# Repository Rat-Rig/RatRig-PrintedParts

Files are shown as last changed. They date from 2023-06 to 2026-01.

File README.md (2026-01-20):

<a href="https://ratrig.com/">
    RatRig logo RatRig
</a>

# Printed Parts Repository

## Overview
This repository contains STL files pertaining to all existing, as well as obsolete, 3D-printed elements used in our products.

Each design is named with a unique SKU to distinguish it, along with a version number and a date. In the case where a fresh revision becomes necessary (such as rectifying an issue with the part, significant enhancement, or improving the printability), a new part is released with an incremented version number.

In cases where the part undergoes a complete redesign, the old SKU is retired and a new SKU is assigned to the new design.

In all cases, any STL which has been replaced is relocated into a subfolder labeled "deprecated".

## Repository Layout
- Generic parts which are shared across projects are stored either in 'Alignment Tools' or 'Miscellaneous'
- Unique parts for each project are stored in the project subfolder
- Deprecated parts are stored within a 'Deprecated' subfolder
```
├── Alignment-Tools/
│   ├── PP000001-align_2020_mgn12_V01_20230627.stl
│   ├── PP000002-align_2020_mgn15_V01_20230627.stl
│   └── ...
├── ...
├── V-Core-3.1/
├── V-Hive/
└── V-Minion/
    ├── Deprecated/
    │   └── PP000028-shroud_V01_20230628.stl
    ├── PP000013-40mm_fan_cage_V01_20230628.stl
    └── ...
```
## Downloads
Individual STL files can be downloaded directly from this repository. Alternately, printed part packs for each product can be downloaded at [files.ratrig.com](https://files.ratrig.com/printed_parts/).

## License
All files contained within this repository are licensed under the [Creative Commons Attribution-NonCommercial-ShareAlike 4.0 International Public License](https://creativecommons.org/licenses/by-nc-sa/4.0/). See LICENSE for the full details.

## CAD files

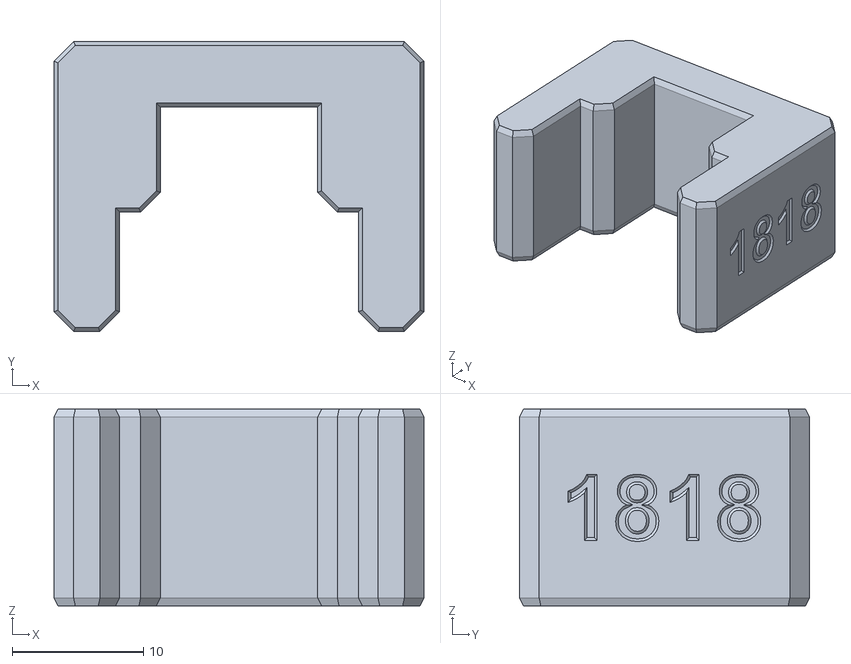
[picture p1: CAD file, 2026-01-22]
Alignment-Tools/PP000407-align_1818_mgn12_V01_20251020.stl
28.2 x 22.1 x 15.0

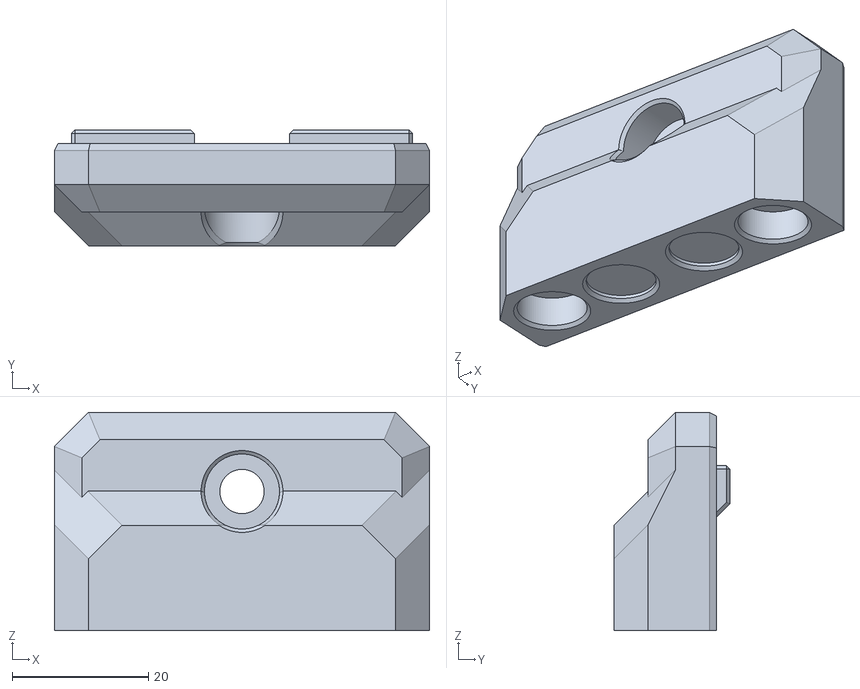
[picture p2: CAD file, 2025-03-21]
CNC-Enclosure/PP000385-cnc_enclosure_magnet_frame_3030_V01_20250122.stl
55.0 x 17.0 x 32.0

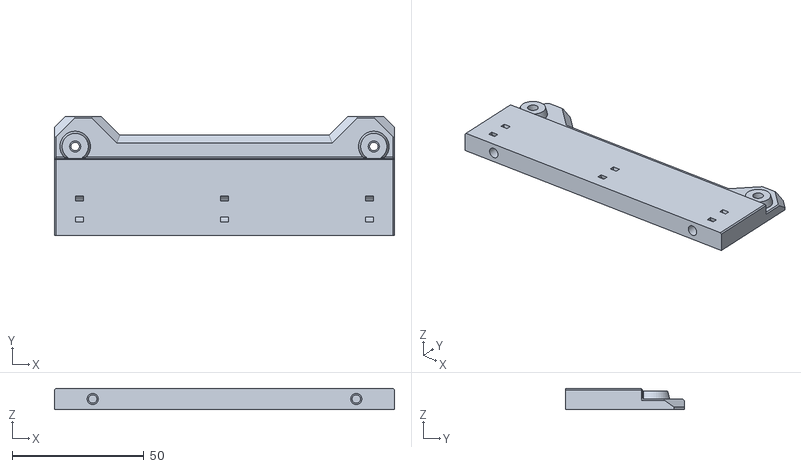
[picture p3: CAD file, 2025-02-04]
Compact-CNC-Electronics-Enclosure/PP000371-compact_cnc_electronics_btt_rodent_V02_20250131.stl
129.0 x 45.0 x 8.00

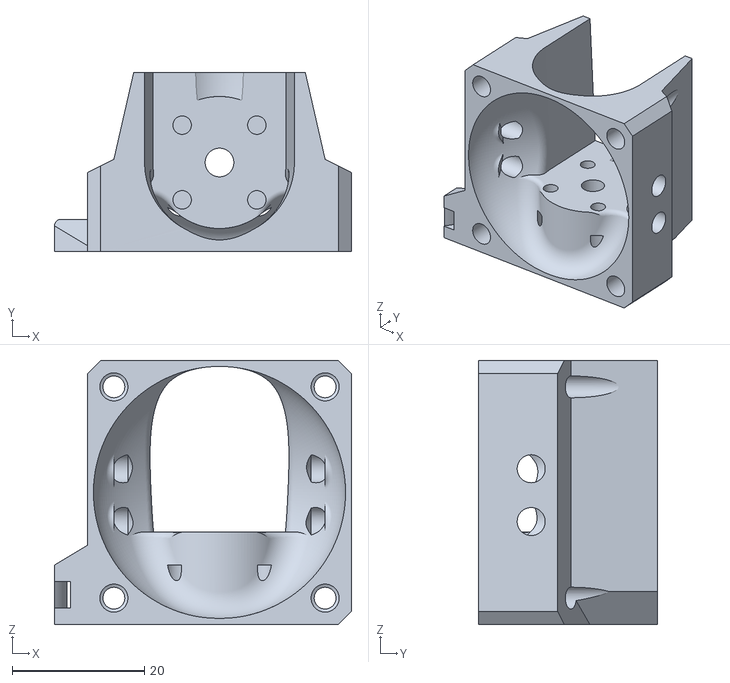
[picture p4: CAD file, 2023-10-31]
EVA-3.0.2/PP000260-hotend_rapido_fi_V01_20231031.stl
45.0 x 27.1 x 40.0

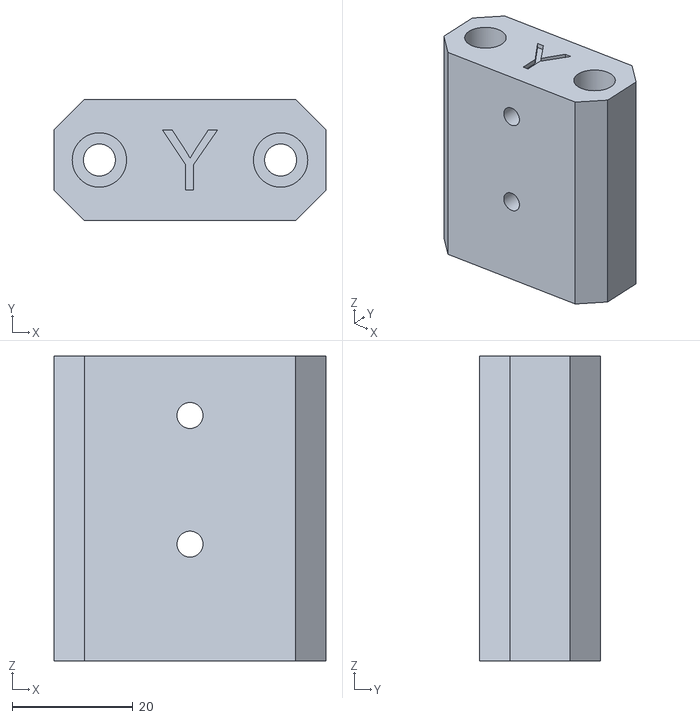
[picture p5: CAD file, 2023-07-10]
KillerBee/PP000070-K-Y-Axis-Gantry-DragChain-Mount_V01_20230710.stl
45.0 x 20.0 x 50.5

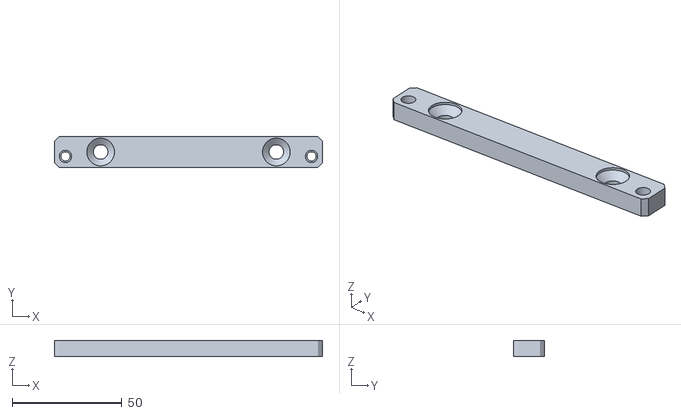
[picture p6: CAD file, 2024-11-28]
Mill/PP000382-mill_vfd_mount_V01_20241127.stl
122.0 x 14.0 x 7.50

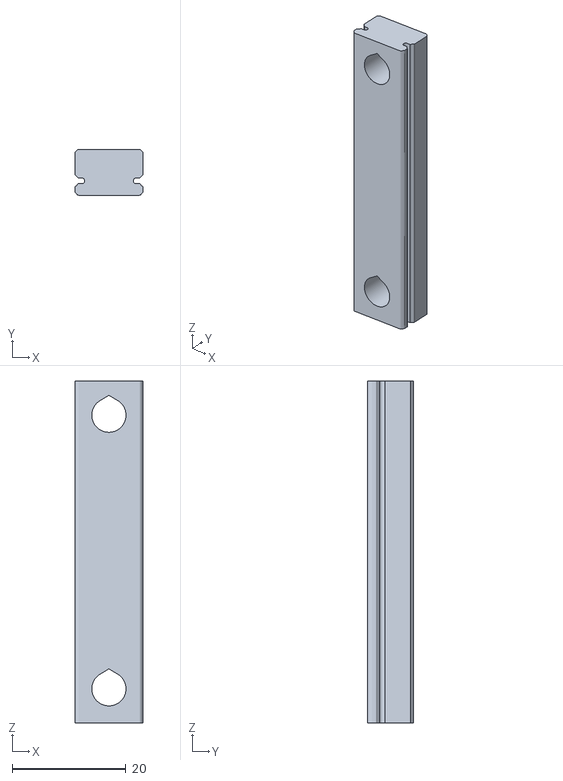
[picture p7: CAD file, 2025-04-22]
Miscellaneous/PP000390-mgn12_carriage_holder_V01_20250422.stl
12.0 x 8.00 x 60.0

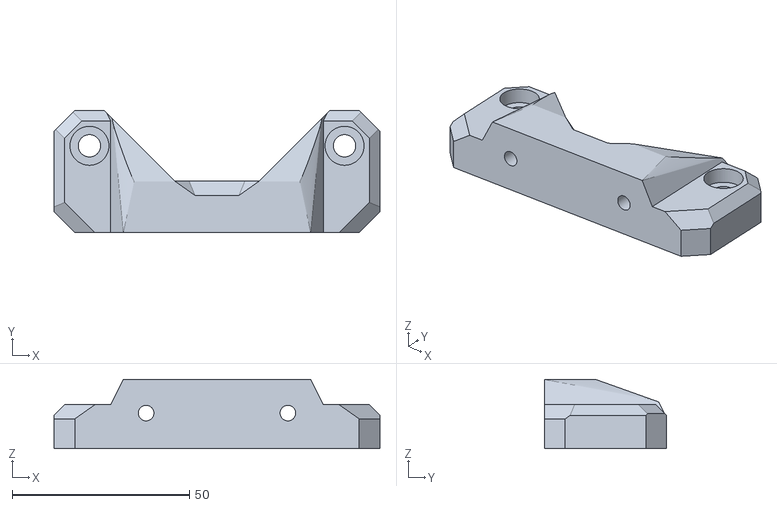
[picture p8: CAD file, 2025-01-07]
Rat-Pack/PP000378-ratpack_mount_large_V01_20241115.stl
92.0 x 34.5 x 19.5

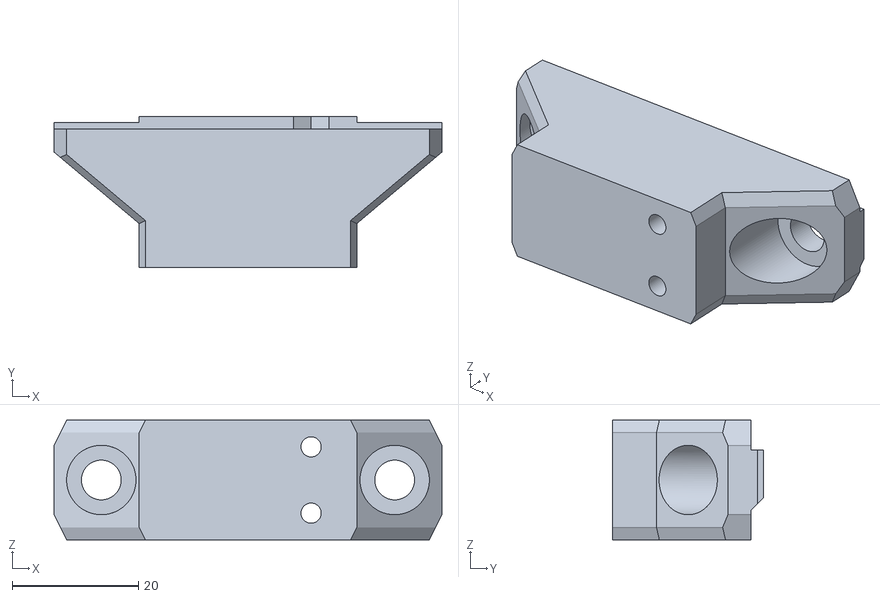
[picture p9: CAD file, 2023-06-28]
StrongHold-ONE/PP000055-sh_y_endstop_mount_V01_20230628.stl
61.5 x 24.0 x 19.0

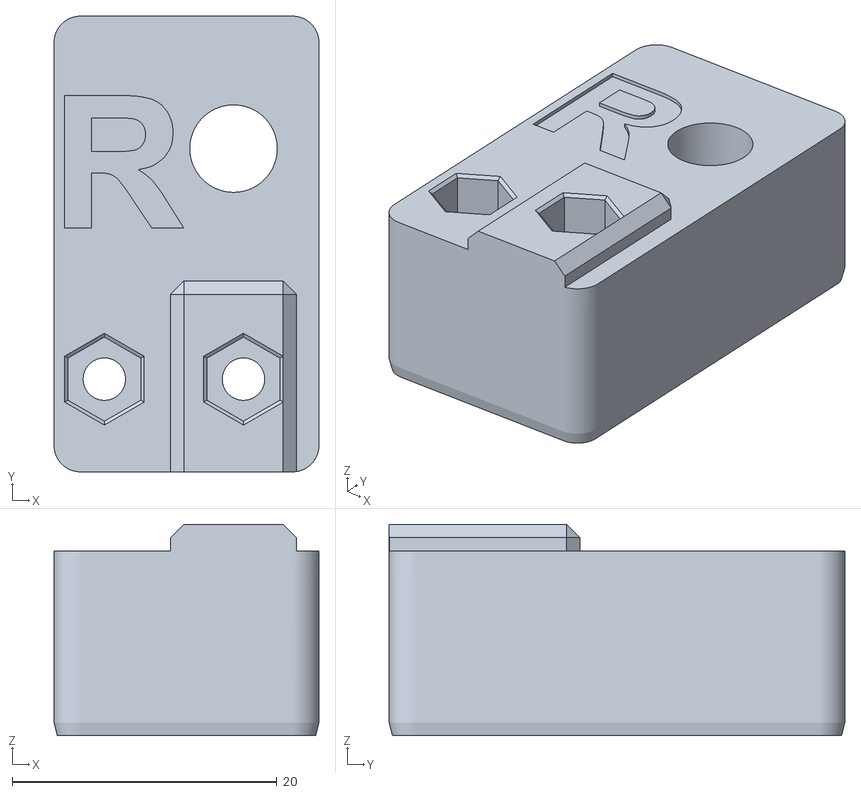
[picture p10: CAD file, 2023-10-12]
StrongHold-PRO/PP000242-sh_pro_y_endstop_right_V01_20231012.stl
20.0 x 34.4 x 15.9

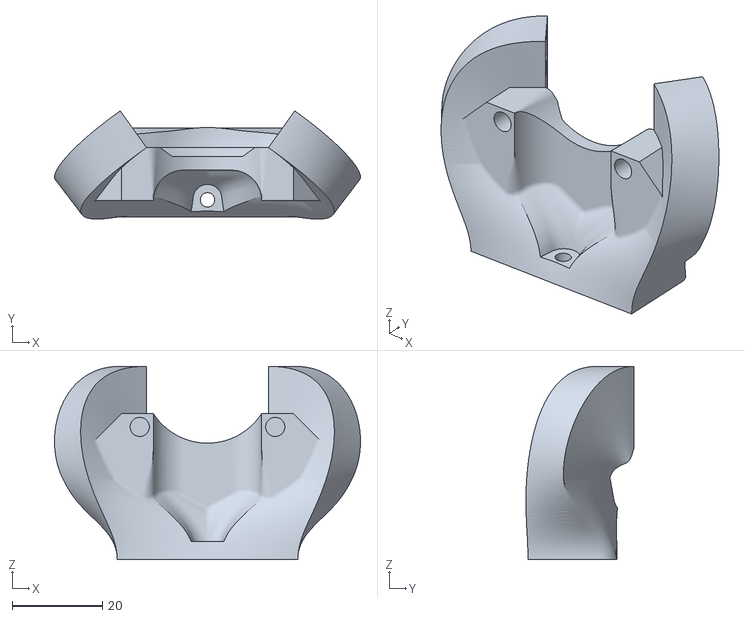
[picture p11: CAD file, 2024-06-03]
Toolheads/Rat Rig V-Core 3.1/PP000348-rr_toolhead_vc3_duct_V01_20240531.stl
67.8 x 24.0 x 42.8

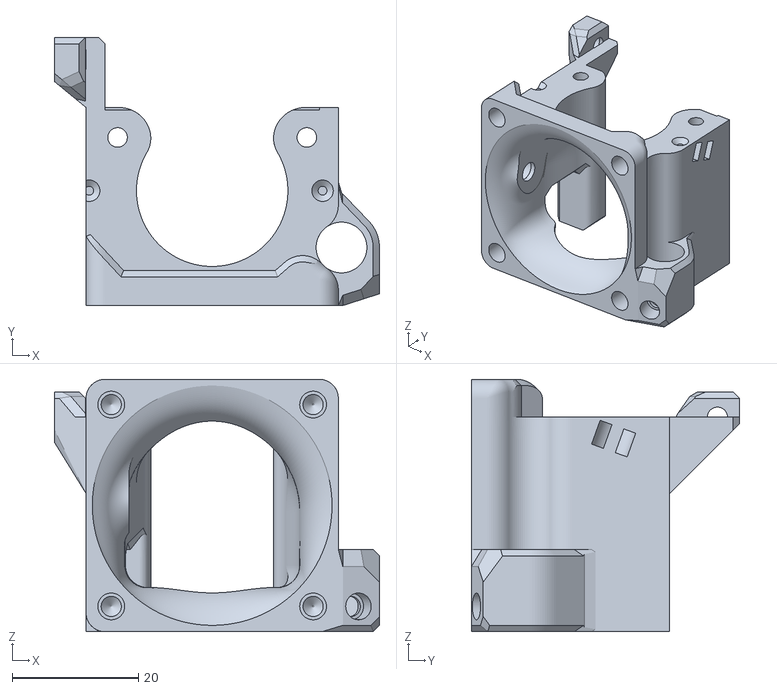
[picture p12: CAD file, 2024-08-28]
Toolheads/Rat Rig V-Core 4.0/PP000316-rr_toolhead_vc4_front_idex_t0_V01_20240813.stl
51.5 x 42.5 x 40.0

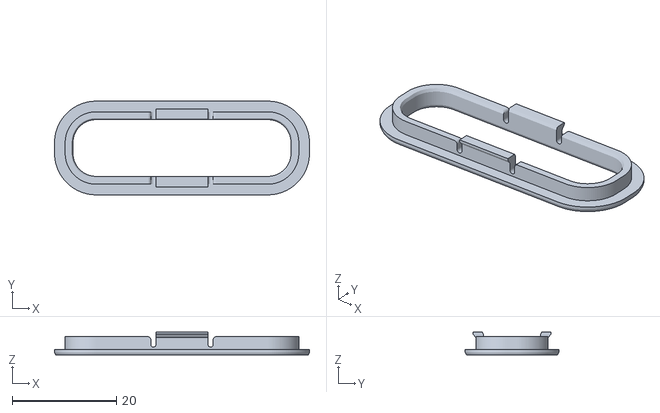
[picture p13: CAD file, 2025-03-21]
Universal-CNC-Electronics-Enclosure/PP000386-ucee_grommet_45mm_V01_20250226.stl
49.0 x 18.0 x 4.40

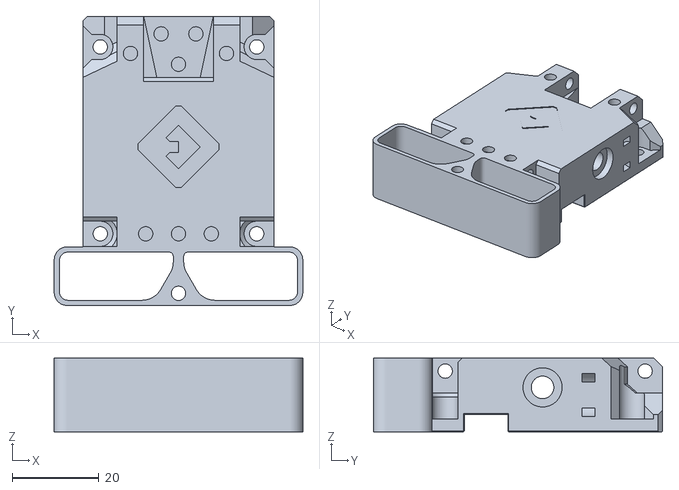
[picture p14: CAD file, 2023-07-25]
V-Core 3.1 IDEX/PP000197-idex_eva3_back_x1_V01_20230724.stl
57.2 x 66.5 x 17.0

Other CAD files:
V-Core-3.0/PP000091-magnet_clip_V01_20230710.stl
V-Core-3.1/PP000287-shelf_support_3.1_V01_20240116.stl
V-Core-3.2H/PP000344-vc32h_tensioner_body_right_V01_20250702.stl
V-Core-4.0/PP000393-vc4_x-endstop_guard_V01_20250716.stl
Alignment-Tools/PP000001-align_2020_mgn12_V01_20230627.stl
Alignment-Tools/PP000002-align_2020_mgn15_V01_20230627.stl
Alignment-Tools/PP000003-align_3030_mgn12_V01_20230627.stl
Alignment-Tools/PP000004-align_3030_mgn15_V01_20230627.stl
Alignment-Tools/PP000005-align_3030_hg15_V01_20230627.stl
Alignment-Tools/PP000006-align_3030_hg25_V01_20230627.stl
Alignment-Tools/PP000007-align_4040_hg15_V01_20230627.stl
Alignment-Tools/PP000008-align_4040_hg25_V01_20230627.stl
Alignment-Tools/PP000009-align_40120_mgn15_V01_20230628.stl
Alignment-Tools/PP000010-align_40120_mgn15_dual_V01_20230628.stl
Alignment-Tools/PP000011-align_40120_hg15_V01_20230628.stl
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

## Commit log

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2023-07-03 Move several VM 1.0 parts to Miscellaneous
    [PP000014-3030_end_cap.stl, PP000015-3030_spool_holder.stl, PP000029-ratrig_eva_shroud.stl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]
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2023-07-03 Add additional miscellaneous parts
    [PP000094-panel_collar.stl, PP000095-panel_collar_nut.stl, PP000108-electronics_wire_guide.stl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]
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2023-07-07 Fix duplicate SKU numbers
    [PP000038-x_motor_cage.stl, PP000177-electronics_wire_guide_rear_hightower.stl]
2023-07-10 Fix STLs exported in metres
    [PP000043-y_endstop_mount.stl, PP000076-back_spine_300.stl, PP000077-back_spine_400.stl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]
2023-07-10 Fix STLs exported in the incorrect orientation
    [PP000059-sh_pro_x_dragchain_mount_cap.stl, PP000070-K-Y-Axis-Gantry-DragChain-Mount.stl, PP000091-magnet_clip.stl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]
2023-07-12 Add a second 3030_end_cap.stl
    This is one of the few parts we provide in multiple colours.
    Use a second SKU for the alternate colour variant.
    [PP000179-3030_end_cap.stl]
2023-07-14 Fix two filename typos
    [PP000137-xy_motor_support_left_3.1.stl, PP000138-xy_motor_support_right_3.1.stl]
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2023-07-27 Correct EVA version (3.0.1 > 3.0.2)
    [PP000141-40mm_fan_inlet.stl, PP000142-back_core_xy.stl, PP000143-bl_touch_mount.stl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]
2023-07-31 VC3.1: Update lead_srew_constraint_front
    Re-introduce the missing L/R legends
    [PP000111-lead_screw_constraint_front_left_3.1.stl, PP000112-lead_screw_constraint_front_right_3.1.stl]
2023-08-02 Misc: Update rr_octopus_cooling_fan_mount
    Add 1 extra layer to the fan grille (0.6mm > 0.9mm)
    [PP000118-rr_octopus_cooling_fan_mount.stl]
2023-10-12 SH PRO: Add second Y-axis endstop mount
    New SKUs:
    - PP000241 - sh_pro_y_endstop_left
    - PP000242 - sh_pro_y_endstop_right
    Deprecates:
    - PP000064 - sh_pro_y_endstop_mount
    [PP000064-sh_pro_y_endstop_mount.stl, PP000241-sh_pro_y_endstop_left.stl, PP000242-sh_pro_y_endstop_right.stl]
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2023-11-02 Update PP000221-rr_toolhead_vc3_front.stl
    Minor revision
    - Add an additional 1mm of depth to the bore for the heated insert which secures the probe
    [PP000221-rr_toolhead_vc3_front.stl]
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2023-11-14 Update PP000223-vc3x_umbilical_frame.stl
    - Remove 2mm from the M6 bore to prevent the mounting screws from bottoming out in the extrusion slot
    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
    [PP000223-vc3x_umbilical_frame.stl]
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2024-04-25 Update naming convention on all STLs
    The naming convention for STL files has been updated to include the version number of the part, as well as the date it was released.
    Designs receiving fixes, enhancements, or printability improvements, will now maintain the same SKU and increment the version.
    In cases where a design undergoes a significant redesign, a new SKU will be assigned.
    In all cases, previous versions will be relocated to the "Deprecated" subfolder.
    [PP000001-align_2020_mgn12_V01_20230627.stl, PP000002-align_2020_mgn15_V01_20230627.stl, PP000003-align_3030_mgn12_V01_20230627.stl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]
2024-04-30 Add V-Core 4.0 Toolhead - CoreXY & Hybrid
    [PP000309-rr_toolhead_vc4_back_clamp_V01_20240327.stl, PP000314-rr_toolhead_vc4_front_V01_20240327.stl, PP000315-rr_toolhead_vc4_front_clamp_V01_20240327.stl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]
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2024-05-09 VC4.0: Update PP000284-vc4_ptfe_guide_upper
    Updated to V02:
    - Added an additional 2mm of depth to the screw threads for the PC4-M10 PTFE fitting
    [PP000284-vc4_ptfe_guide_upper_V01_20240416.stl, PP000284-vc4_ptfe_guide_upper_V02_20240509.stl]
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2024-05-22 VC4.0: Update PP000295 & PP000296-vc4_xy_trims
    - Added an additional 0.5mm of depth to the bores which house the M5 countersunk screw tips. This adds clearance for imperfect bridging, or minor variances mechanical parts.
    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
    [PP000295-vc4_xy_trim_left_V01_20240319.stl, PP000295-vc4_xy_trim_left_V02_20240522.stl, PP000296-vc4_xy_trim_right_V01_20240319.stl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]
2024-06-03 VC4.0 Toolhead: Add PP000252-rr_toolhead_vc3_fan_grille
    To avoid confusion regarding missing files when cloning / downloading from GitHub, we're now storing copies of STLs in multiple locations when that design is shared among projects.
    This is a duplicate of PP000252-rr_toolhead_vc3_fan_grille_V01_20231023.stl found in the VC3.1 toolhead. No design changes have been made.
    [PP000252-rr_toolhead_vc3_fan_grille_V01_20231023.stl]
2024-06-03 VC3.1 Toolhead: Rename PP000291-rr_toolhead_vc3_umbilical
    Drop beta2 from the name as this part remains identical for the final design
    [PP000291-rr_toolhead_vc3_umbilical_V01_20231218.stl]
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2024-07-19 VC4.0: Clarify electronics enclosure corner naming
    Current printed parts are for version 1.1 of the VC4 electronics enclosure.
    This is the revision with powder coated 1.5mm thick steel side panels and lid.
    [PP000329-vc4_electronics_1.1_corner_V01_20240424.stl, PP000335-vc4_electronics_1.1_corner_hole_V01_20240424.stl]
2024-07-19 VC4.0: Update PP000335-vc4_electronics_1.1_corner_hole
    - Increased the diameter of the pass-thru hole to 18mm, allowing more clearance for shielded or reinforced ethernet cables
    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
    [PP000335-vc4_electronics_1.1_corner_hole_V01_20240424.stl, PP000335-vc4_electronics_1.1_corner_hole_V02_20240719.stl]
2024-07-19 VC4.0: Add PP000353-vc4_electronics_1.0_corner_hole
    This variant is compatible with the version 1.0 electronics enclosure.
    This is the revision with anodised 2.5mm aluminium side panels and lid.
    [PP000353-vc4_electronics_1.0_corner_hole_V01_20240719.stl]
2024-08-14 VC4.0: Deprecate PP000332-vc4_electronics_duct
    This design has been deprecated due to the v1.2 aluminium enclosure moving to a single 120mm fan.
    [PP000332-vc4_electronics_duct_V01_20240422.stl]
2024-08-14 VC4.0: Deprecate PP000322-vc4_printed_handle
    This design has been deprecated due to the V-Core 4.0 kit moving to cast aluminium handles
    [PP000322-vc4_printed_handle_V01_20240319.stl]
2024-08-14 VC4.0: Update PP000321-vc4_magnet_handle
    Updated the hole spacing for the new aluminium handles
    [PP000321-vc4_magnet_handle_V01_20240320.stl, PP000321-vc4_magnet_handle_V02_20240612.stl]
2024-08-14 VC4.0: Electronics Enclosure v1.2 updates
    Version 1.2 of the aluminium electronics enclosure moves to a new cooling design using a single 120mm fan.
    New designs:
    PP000352-vc4_electronics_1.2_corner
    PP000354-vc4_electronics_1.2_corner_hole
    - New corner designs were needed to support the v1.2 electronics enclosure.
    Updated V03:
    PP000301-vc4_adapter_octopus
    - The Octopus adapter was modified to be lower. This allows clearance below the 120mm fan.
    [PP000301-vc4_adapter_octopus_V02_20240327.stl, PP000301-vc4_adapter_octopus_V03_20240612.stl, PP000352-vc4_electronics_1.2_corner_V01_20240719.stl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]
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2024-09-25 VC4.0: Update PP000355-vc4_vaoc_body
    - Increased the diameter of the bore for the POM spacer from 9.1mm to 9.2mm
    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
    [PP000355-vc4_vaoc_body_V01_20240828.stl, PP000355-vc4_vaoc_body_V02_20240923.stl]
2024-11-04 VC4.0: Update vc4_3060_trims
    PP000323-vc4_3060_trim_front
    PP000324-vc4_3060_trim_rear
    PP000333-vc4_3060_trim_diffuser
    - Design updated for compatibility with updated 3060 brackets
    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
    [PP000323-vc4_3060_trim_front_V01_20240429.stl, PP000323-vc4_3060_trim_front_V02_20240814.stl, PP000324-vc4_3060_trim_rear_V01_20240429.stl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]
2024-11-04 VC4.0: Update cable_guide 4, 5 & cross
    PP000304-vc4_cable_guide_4
    PP000305-vc4_cable_guide_5
    PP000306-vc4_cable_guide_cross
    - Increased surface area to aid bed adhesion
    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
    [PP000304-vc4_cable_guide_4_V01_20240216.stl, PP000304-vc4_cable_guide_4_V02_20241104.stl, PP000305-vc4_cable_guide_5_V01_20240216.stl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]
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2024-11-20 CCEE: Update PP000372-compact_cnc_electronics_psu
    - Reduced cut-out depth to increase part strength
    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
    [PP000372-compact_cnc_electronics_psu_V01_20241113.stl, PP000372-compact_cnc_electronics_psu_V02_20241120.stl]
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2024-12-12 Mill: Replace PP000010 with PP000009
2024-12-13 VC4.0: Update PP000355-vc4_vaoc_body
    Updated to V03:
    - Design updated for v1.1 of the VAOC module
    [PP000355-vc4_vaoc_body_V02_20240923.stl, PP000355-vc4_vaoc_body_V03_20241104.stl]
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2025-02-04 CCEE: Update PP000371-compact_cnc_electronics_btt_rodent
    - Added an additional 4mm of clearance for the height of the BTT Rodent
    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
    [PP000371-compact_cnc_electronics_btt_rodent_V01_20241113.stl, PP000371-compact_cnc_electronics_btt_rodent_V02_20250131.stl]
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2025-06-26 VC4.0: Refinement of printed parts
    Several of the V-Core 4.0 printed parts have been updated to improve printability, fitment of fasteners, or improve clearances where printed parts fit together. The following is a full list of the parts which have changed, along with specifics on the changes made to each:
    PP000264-vc4_arm_cable - Updated to V02:
    - M3 through holes increased from 3.2mm to 3.4mm
    PP000265-vc4_arm_front - Updated to V02:
    PP000266-vc4_arm_rear - Updated to V03:
    - M3 through holes increased from 3.2mm to 3.4mm
    - M4 through holes (HG15 mounting) increased from 4.3mm to 4.5mm
    - Added “teardrop” to HG15 mounting holes
    - Increased decoupler “notch” by 0.1mm to match new M4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
    [PP000264-vc4_arm_cable_V01_20240408.stl, PP000264-vc4_arm_cable_V02_20250602.stl, PP000265-vc4_arm_front_V01_20240319.stl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]
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2026-01-22 Add V-Core 4.1 (Full kit, IDEX and Upgrade)
    Includes deprecated parts
    PP000402-rr_toolhead_vc41_duct - Updated to V02:
    - Improved printability
    - Added 3mm clearance chamfer to back edge
    PP000406-vc41_z_constraint - Updated to V02:
    - Design update to increase clearance for Z-axis linear rail carriage variance
    PP000408-rr_toolhead_vc41_relief - Updated to V02:
    Increased grip on the Orbitool O2S umbilical connector
    [PP000392-vc41_xy_spacer_V01_20251031.stl, PP000393-vc4_x-endstop_guard_V02_20251022.stl, PP000401-rr_toolhead_vc41_front_V01_20251027.stl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]
2026-01-22 Deprecate PP000393-vc4_x-endstop_guard V01
    PP000393-vc4_x-endstop_guard - Updated to V02:
    - V02 exists in the V-Core 4.1 project
    - Added support for the V-Core 4.1 toolhead
    [PP000393-vc4_x-endstop_guard_V01_20250716.stl]
2026-01-23 Update PP000406-vc41_z_constraint
    Incorrect STL previously uploaded. This file overwrites V02
    No dimensional or functional changes, only a small printability improvement
    [PP000406-vc41_z_constraint_V02_20260121.stl]
